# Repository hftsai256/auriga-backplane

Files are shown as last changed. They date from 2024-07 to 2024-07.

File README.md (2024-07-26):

# Auriga Backplane

The project is reverse-engineered from the original backplane to house dual 2.5" SSDs into one 3.5" HDD bay with
[this mounting bracket](https://www.corsair.com/us/en/p/pc-components-accessories/cssd-brkt2/dual-ssd-mounting-bracket-aca-a-black-cssd-brkt2).
All mechanical dimensions are hand-measured and "rounded to a reasonable factor in metric units."

# Known Issues

The pin layout of the LED connectors are reversed (as of v0.5.) Therefore one side of the ribbon cable must be
reversed in order to activate the LED indicators.

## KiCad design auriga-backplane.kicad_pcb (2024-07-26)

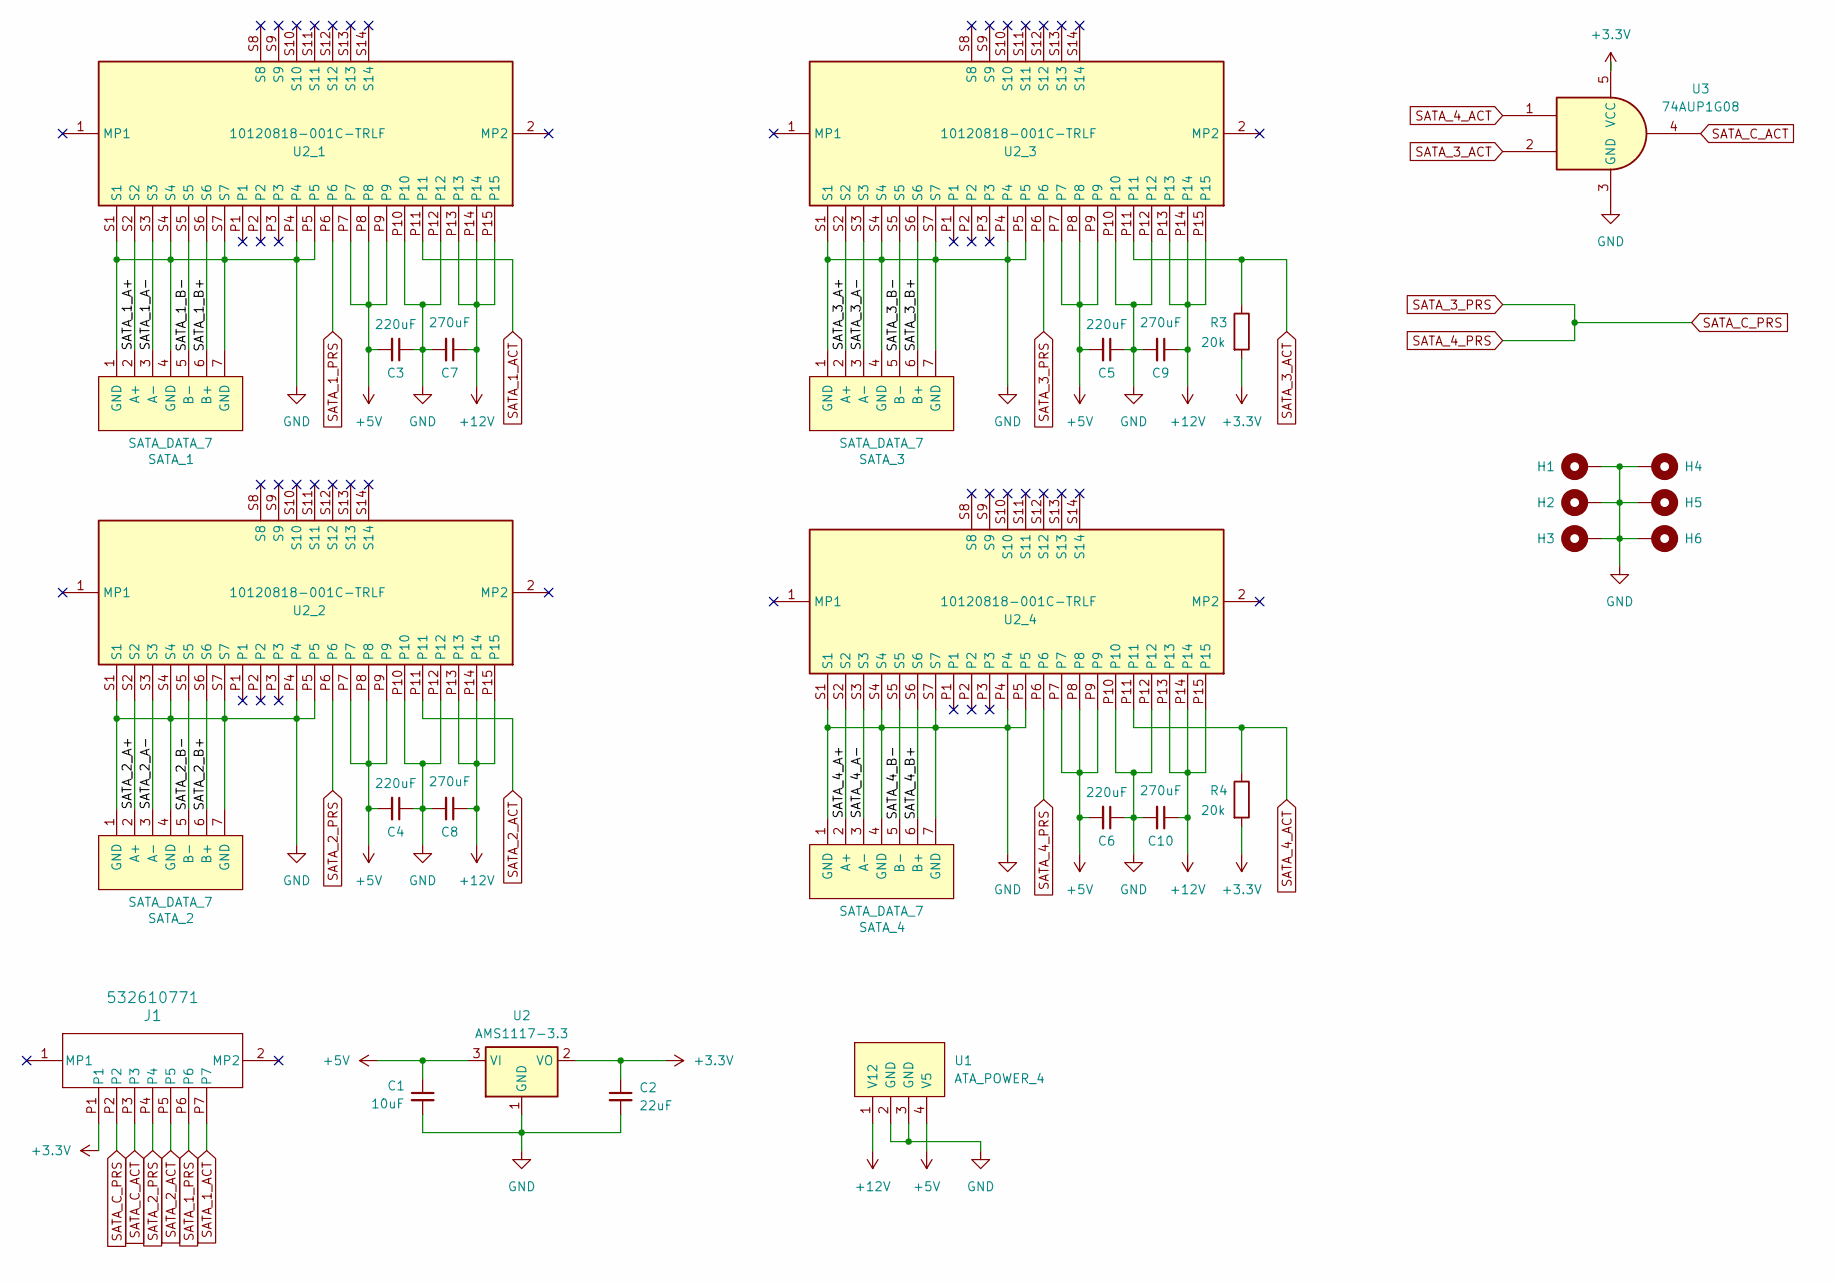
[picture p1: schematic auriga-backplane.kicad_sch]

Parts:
C1: 10uF; C_0805_2012Metric
C2: 22uF; C_0402_1005Metric
C3, C4, C5, C6: 220uF; C_1210_3225Metric_Pad1.33x2.70mm_HandSolder
C7, C8, C9, C10: 270uF; CP_Elec_6.3x7.7
H1, H2, H3, H4, H5, H6: MountingHole_Pad; MountingHole_3.7mm_Pad_TopBottom_Thin
J1: 532610771; CON_532610771
R3, R4: 20k; R_0402_1005Metric
SATA_1, SATA_2, SATA_3, SATA_4: SATA_DATA_7
U1: ATA_POWER_4
U2: AMS1117-3.3; SOT-223-3_TabPin2
U2_1, U2_2, U2_3, U2_4: 10120818-001C-TRLF; 10120818001CTRLF; Manufacturer_Part_Number 10120818-001C-TRLF
U3: 74AUP1G08; SOT-23-5

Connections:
+3.3V: C2.1, J1.P1, R3.2, R4.2, U2.2 (VO), U3.5 (VCC)
+5V: C1.1, C3.2, C4.2, C5.2, C6.2, U1.4 (V5), U2.3 (VI), U2_1.P7, U2_1.P8, U2_1.P9, U2_2.P7, U2_2.P8, U2_2.P9, U2_3.P7, U2_3.P8, U2_3.P9, U2_4.P7, U2_4.P8, U2_4.P9
+12V: C7.1, C8.1, C9.1, C10.1, U1.1 (V12), U2_1.P13, U2_1.P14, U2_1.P15, U2_2.P13, U2_2.P14, U2_2.P15, U2_3.P13, U2_3.P14, U2_3.P15, U2_4.P13, U2_4.P14, U2_4.P15
/SATA_1_A+: SATA_1.2 (A+), U2_1.S2
/SATA_1_A-: SATA_1.3 (A-), U2_1.S3
/SATA_1_B+: SATA_1.6 (B+), U2_1.S6
/SATA_1_B-: SATA_1.5 (B-), U2_1.S5
/SATA_2_A+: SATA_2.2 (A+), U2_2.S2
/SATA_2_A-: SATA_2.3 (A-), U2_2.S3
/SATA_2_B+: SATA_2.6 (B+), U2_2.S6
/SATA_2_B-: SATA_2.5 (B-), U2_2.S5
/SATA_3_A+: SATA_3.2 (A+), U2_3.S2
/SATA_3_A-: SATA_3.3 (A-), U2_3.S3
/SATA_3_B+: SATA_3.6 (B+), U2_3.S6
/SATA_3_B-: SATA_3.5 (B-), U2_3.S5
/SATA_4_A+: SATA_4.2 (A+), U2_4.S2
/SATA_4_A-: SATA_4.3 (A-), U2_4.S3
/SATA_4_B+: SATA_4.6 (B+), U2_4.S6
/SATA_4_B-: SATA_4.5 (B-), U2_4.S5
GND: C1.2, C2.2, C3.1, C4.1, C5.1, C6.1, C7.2, C8.2, C9.2, C10.2, H1.1, H2.1, H3.1, H4.1, H5.1, H6.1, SATA_1.1 (GND), SATA_1.4 (GND), SATA_1.7 (GND), SATA_2.1 (GND), SATA_2.4 (GND), SATA_2.7 (GND), SATA_3.1 (GND), SATA_3.4 (GND), SATA_3.7 (GND), SATA_4.1 (GND), SATA_4.4 (GND), SATA_4.7 (GND), U1.2 (GND), U1.3 (GND), U2.1 (GND), U2_1.P4, U2_1.P5, U2_1.P10, U2_1.P12, U2_1.S1, U2_1.S4, U2_1.S7, U2_2.P4, U2_2.P5, U2_2.P10, U2_2.P12, U2_2.S1, U2_2.S4, U2_2.S7, U2_3.P4, U2_3.P5, U2_3.P10, U2_3.P12, U2_3.S1, U2_3.S4, U2_3.S7, U2_4.P4, U2_4.P5, U2_4.P10, U2_4.P12, U2_4.S1, U2_4.S4, U2_4.S7, U3.3 (GND)
SATA_1_ACT: J1.P7, U2_1.P11
SATA_1_PRS: J1.P6, U2_1.P6
SATA_2_ACT: J1.P5, U2_2.P11
SATA_2_PRS: J1.P4, U2_2.P6
SATA_3_ACT: R3.1, U2_3.P11, U3.2
SATA_3_PRS: J1.P2, U2_3.P6, U2_4.P6
SATA_4_ACT: R4.1, U2_4.P11, U3.1
SATA_C_ACT: J1.P3, U3.4

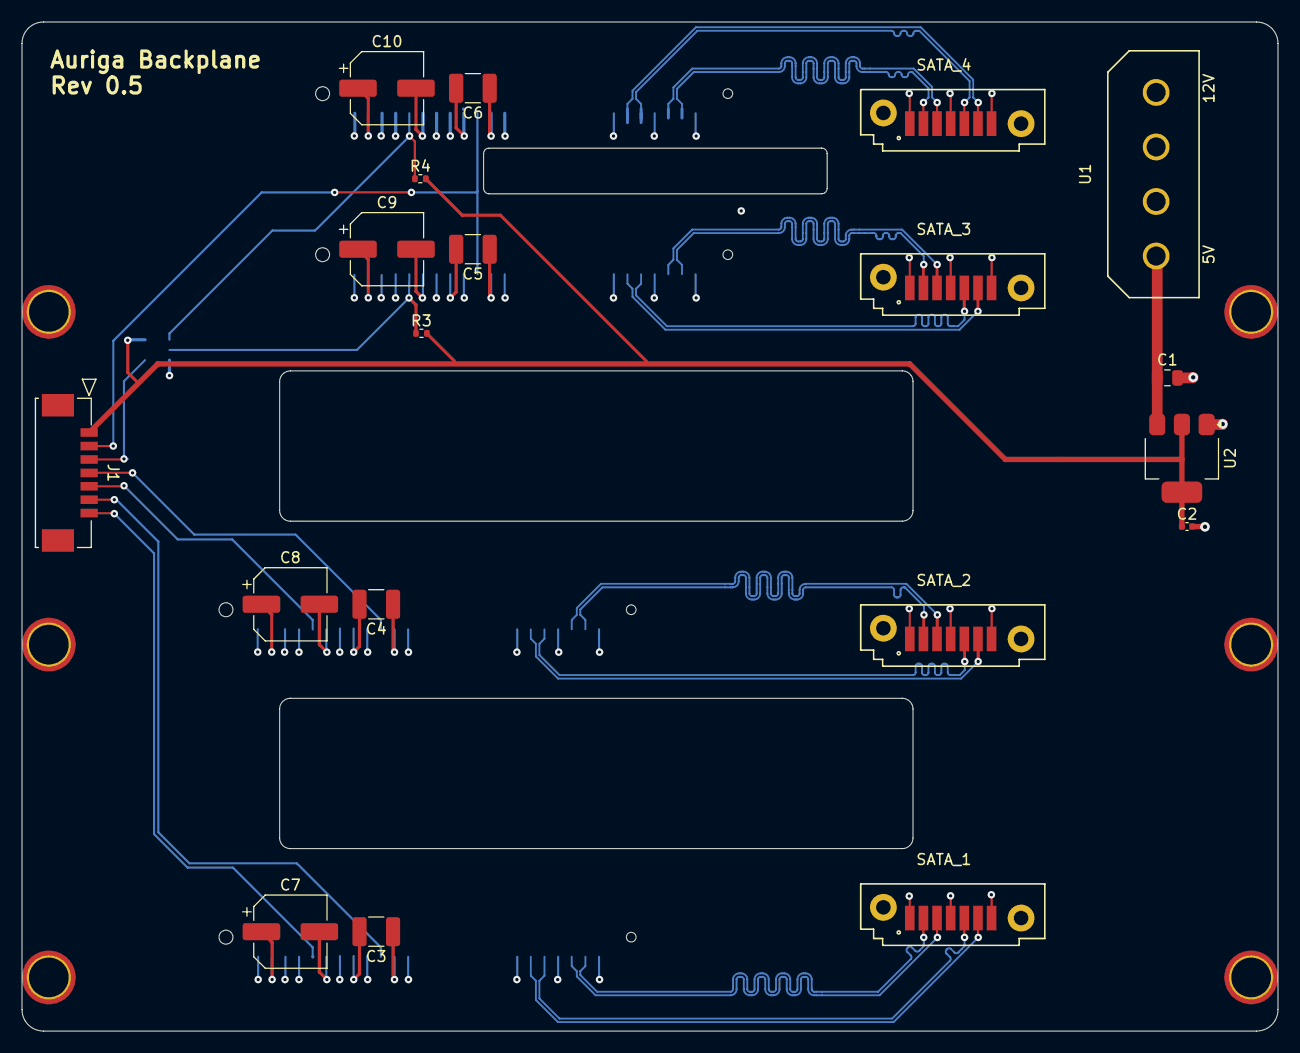
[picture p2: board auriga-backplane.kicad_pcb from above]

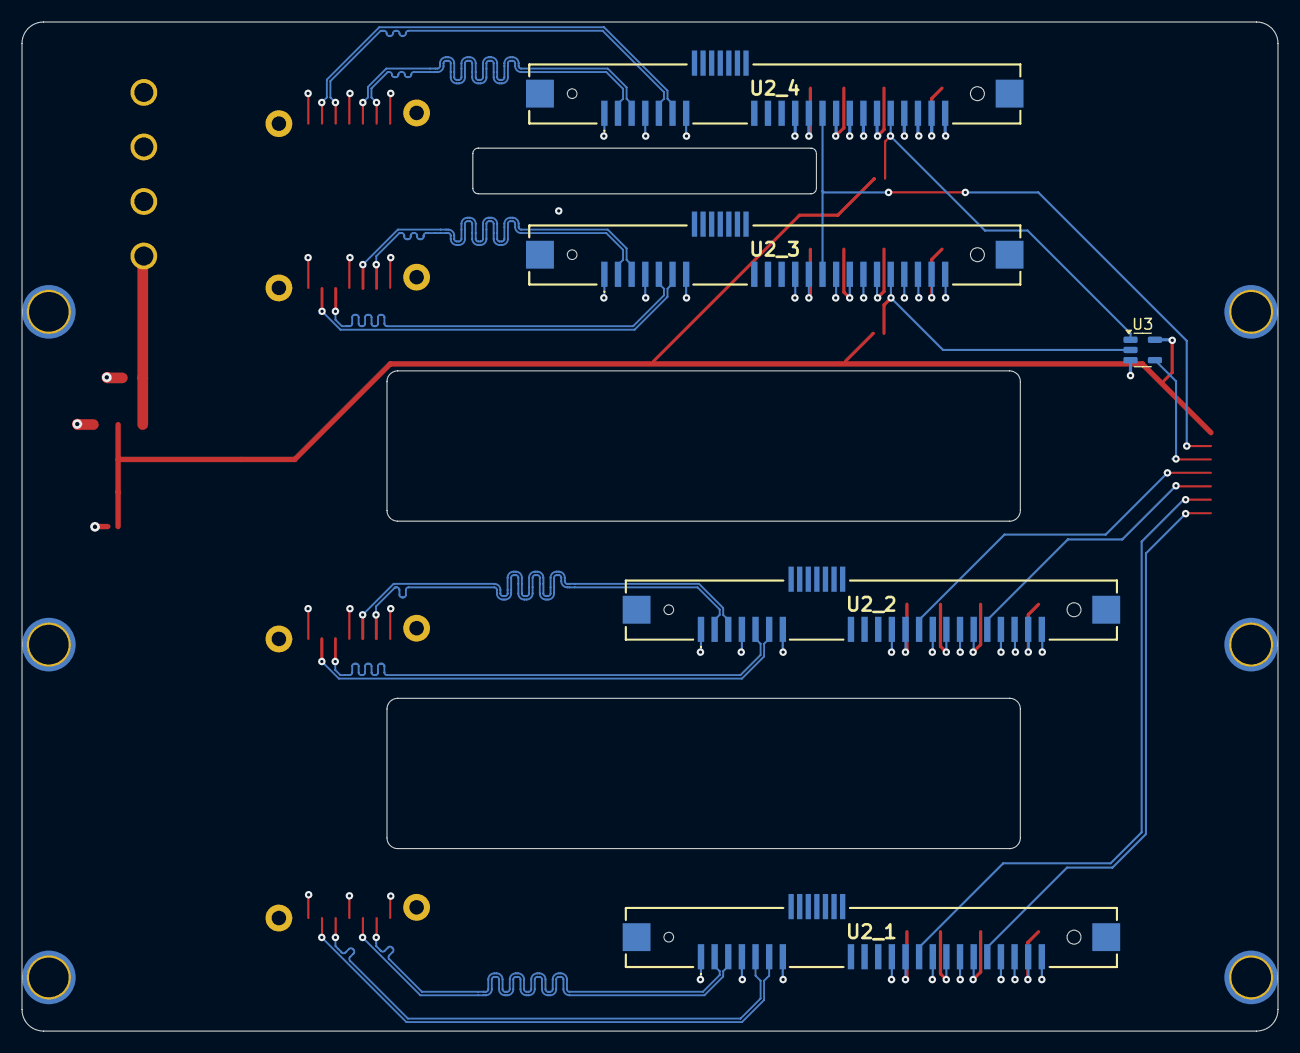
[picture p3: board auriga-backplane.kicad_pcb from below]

Board: 4 copper layers, 117.0 x 94.0 mm, 30 parts (5 on the bottom side), 28 nets.
